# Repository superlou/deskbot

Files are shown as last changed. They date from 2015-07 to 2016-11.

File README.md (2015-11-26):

# deskbot

The boring desktop robot.

# Installation

Install pi-blaster.

    sudo apt-get install python-smbus i2c-tools
    sudo raspi-config

In the config menu, advanced options, enable automatic loading of the I2C kernel module.  Still [had to add](https://forums.adafruit.com/viewtopic.php?f=47&t=74517&sid=16e9d784a04c41fe58b5d3ec6f3fdb2d) the following to /etc/modules:

    i2c-bcm2708
    i2c-dev

May need to do some of [manual configuration steps](https://learn.adafruit.com/adafruits-raspberry-pi-lesson-4-gpio-setup/configuring-i2c).

Test with `sudo i2cdetect -y 0`.

For scipy:
    sudo apt-get install liblapack-dev gfortran
    pip install scipy # or, alternatively the following line
    sudo apt-get install python-scipy # not up-to-date, but installs much faster

Run Servo IK test with `python -m code.servo_test_ik`.

Need a relatively recent install of cython (which takes a long time to build via `pip`).  Required increase swap size per http://raspberrypi.stackexchange.com/questions/70/how-to-set-up-swap-space.

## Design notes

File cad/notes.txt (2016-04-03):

Servo mounting screws: https://www.servocity.com/html/mounting_screws.html
Length: 0.575" - measure directly under the head of the fastener (measures how much is inset in the material)
Screw diameter: 0.087"
Head diameter: 0.235"

https://www.boltdepot.com/fastener-information/Measuring/Measure-Diameter.aspx

Measuring the ones included with the HS-311 kit:
Thread (major) diameter: 0.088, Shank Diameter: 0.082, Root (minor) Diameter: ~0.050

https://www.boltdepot.com/fastener-information/Wood-Screws/Wood-Screw-Diameter.aspx

It's probably 9/16" length, #2 size wood screw.  Hole should be at least 0.600" deep, 1/16" straight bit 0.062" diameter.

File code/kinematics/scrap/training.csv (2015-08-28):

theta0 | theta1 | theta2 | phi0 | phi1 | phi2 | centroid_x | centroid_y | centroid_z | normal_x | normal_y | normal_z
-0.051979459788405125 | -0.4153607124880795 | -0.26255196620026755 | 1.08128773900578 | 0.975005773234984 | 1.12393933345835 | -0.022594617238130905 | 0.010614179645496158 | 0.6323523142335397 | 0.21807871561932096 | 0.3433888640516431 | 0.913523815693466
0.12345850232011135 | 0.10087838873966659 | 0.25844978307539723 | 1.12769162593424 | 1.12680125790354 | 1.08719967708002 | 0.0021035898199976235 | -0.0023250499304069416 | 1.057076878362002 | 0.13716029233399246 | -0.052839453500310656 | 0.9891385374964634
0.023972055089184763 | 0.24487759738520898 | 0.04804075004576591 | 1.1308020782987 | 1.07947775593959 | 1.13601836820659 | -0.006322161821066707 | -0.0017862178089064578 | 1.0026196165669914 | -0.16916325011422875 | -0.12799118372169088 | 0.97724206402524
-0.26988111103215773 | -0.35166023097420485 | 0.13644442227586284 | 1.12419130494064 | 1.02327478709782 | 1.00857168013845 | 0.018590912802977384 | -0.03195552531292881 | 0.7089183238733797 | 0.4727323118827423 | -0.1275076363458139 | 0.8719323161665138
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

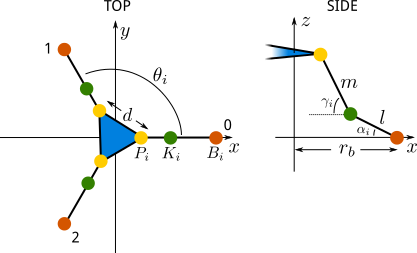
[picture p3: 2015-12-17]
diagrams/forward_kinematic_model.png

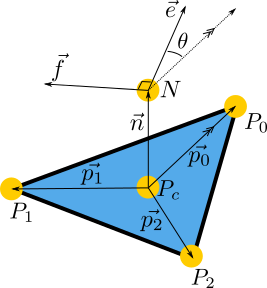
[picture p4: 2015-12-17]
diagrams/head_ik_model.png

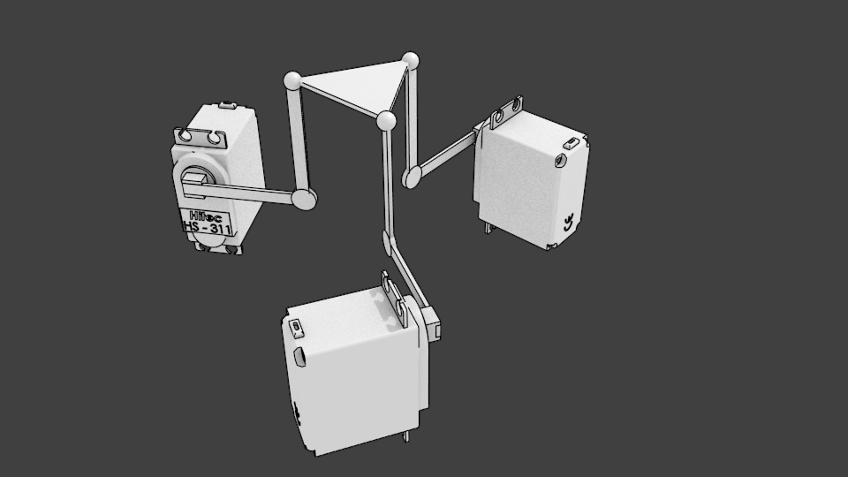
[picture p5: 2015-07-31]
blender/mockup.png

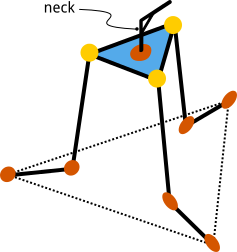
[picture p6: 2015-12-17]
diagrams/system_with_neck.png

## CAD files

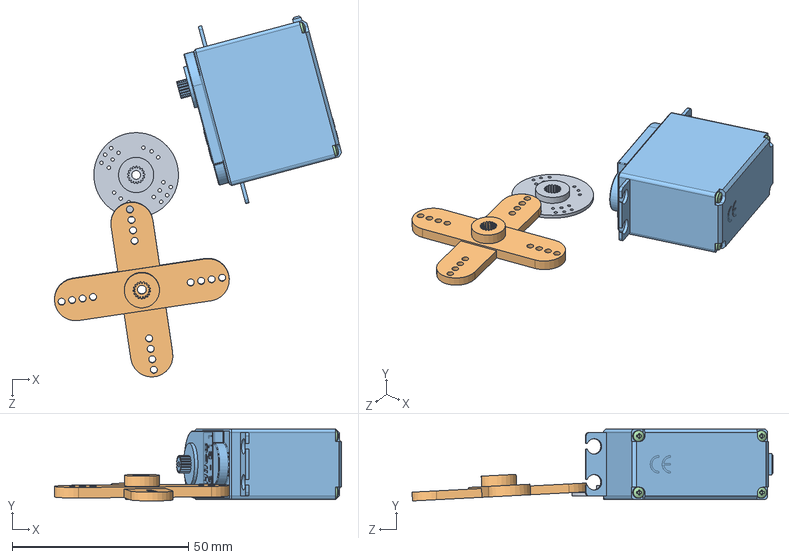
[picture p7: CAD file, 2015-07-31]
cad/servo/Hitec HS-311 Servo Motor/Hitec HS-311.SLDASM
81.4 x 20.4 x 102.3 mm
Spline
Spline 2
Hitec Servo Motor HS-311
pan head cross recess screw_din x 4

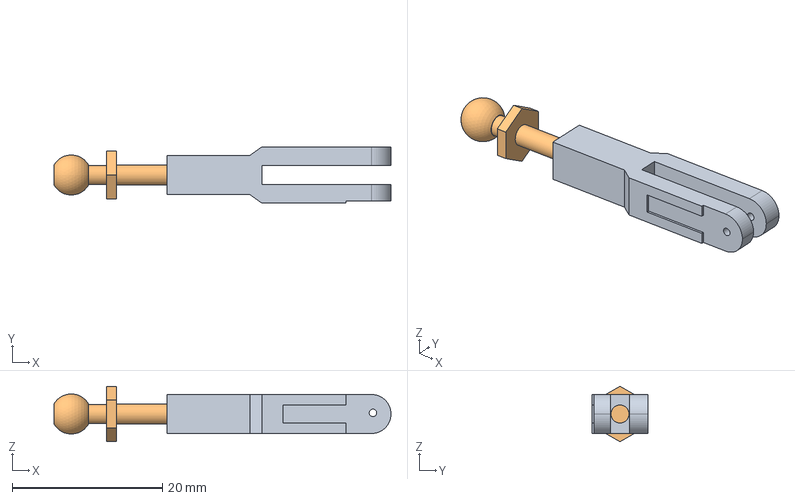
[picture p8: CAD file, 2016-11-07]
cad/clevis_ball_assembly.fcstd
44.9 x 7.50 x 7.39 mm
clevis_01
threaded_ball_01

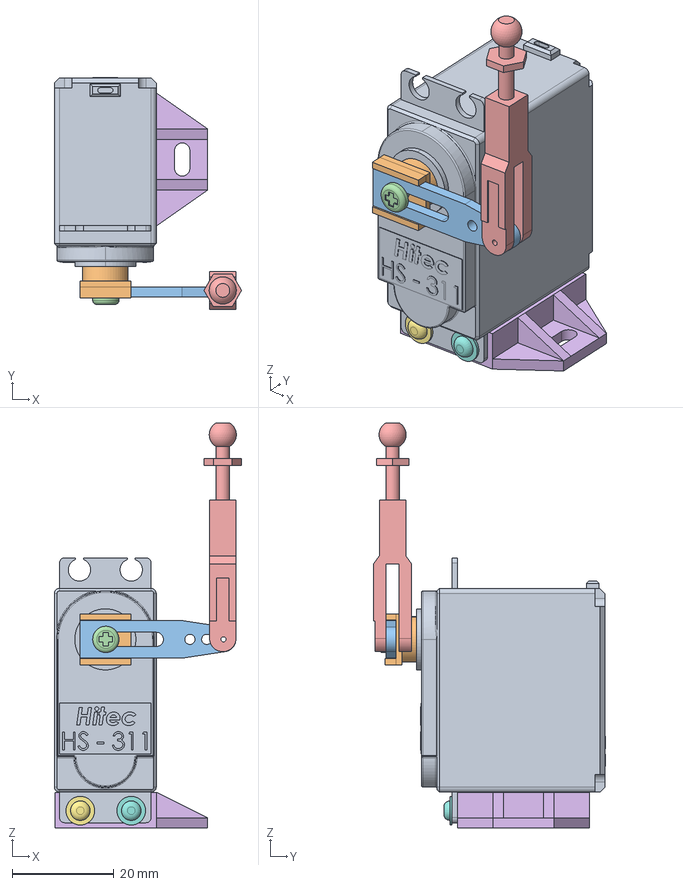
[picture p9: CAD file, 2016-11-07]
cad/servo_assembly.fcstd
36.7 x 45.6 x 79.5 mm
servo_hs_311_01
hs_311_pinion_adapter_01
servo_horn_01
hs_311_pinion_screw_01
clevis_ball_assembly_01
flat_servo_stand_01
hs_311_screw_01
hs_311_screw_01001

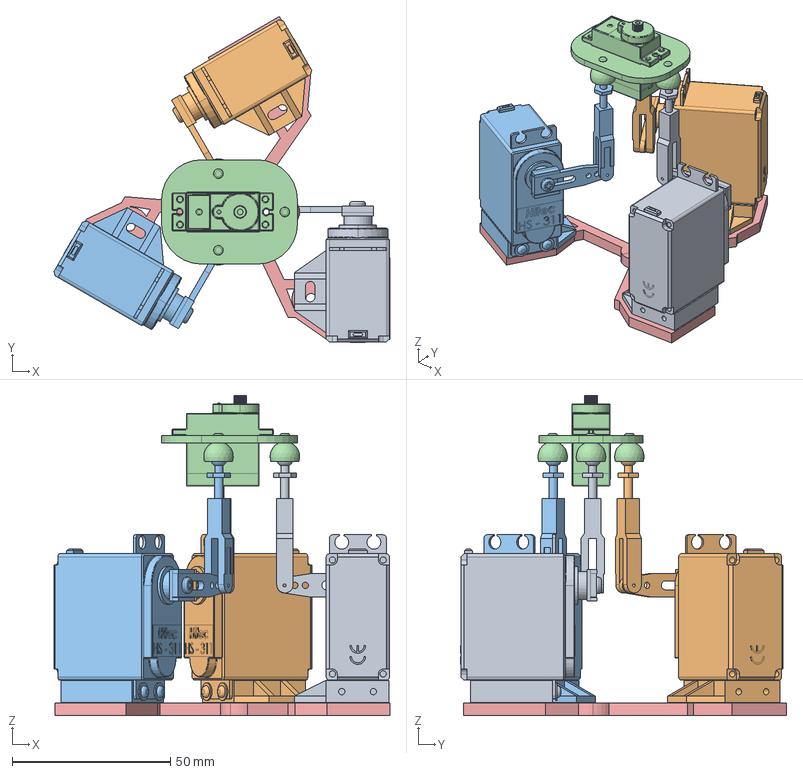
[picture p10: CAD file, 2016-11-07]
cad/kinematics_assembly.fcstd
106.3 x 103.1 x 101.4 mm
servo_assembly_01
servo_assembly_02
servo_assembly_03
head_assembly_01
base_full_01

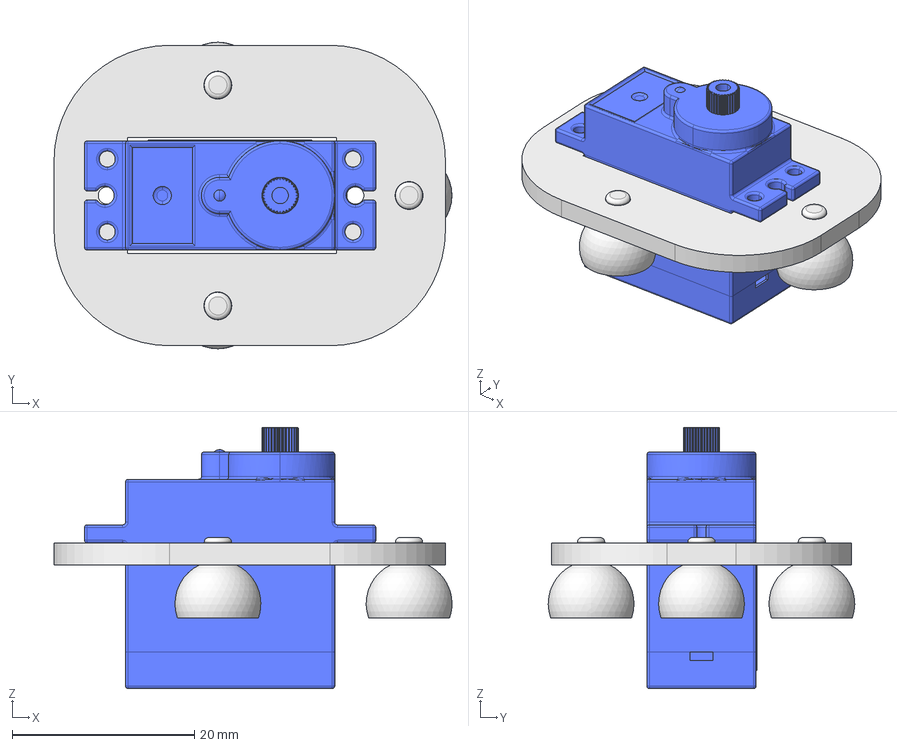
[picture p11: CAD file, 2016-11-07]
cad/head_assembly.fcstd
43.7 x 33.7 x 28.7 mm
head_mount_flat_01
socket_pin_01
socket_pin_02
socket_pin_03
hxt900_01

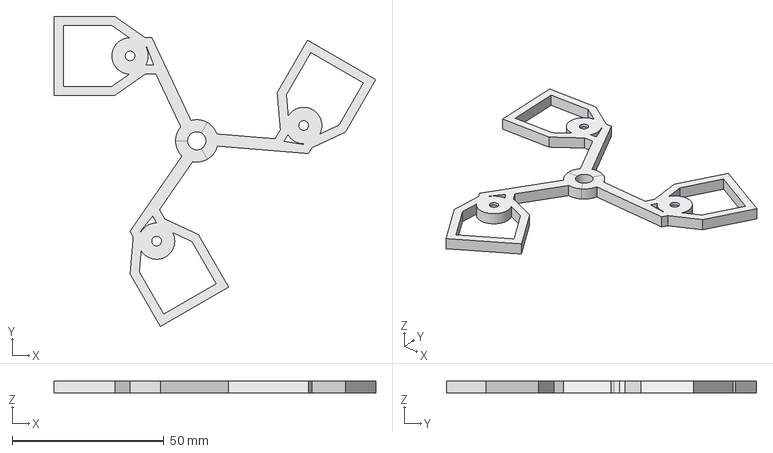
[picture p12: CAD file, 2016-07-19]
cad/base_full.fcstd
106.0 x 102.2 x 4.00 mm

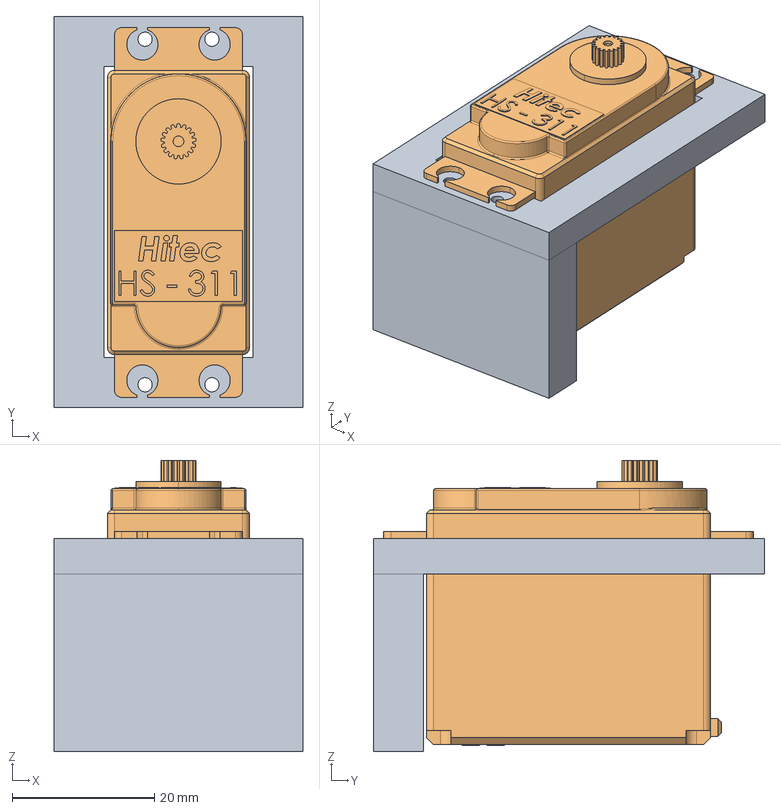
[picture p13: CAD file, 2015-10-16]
cad/vertical_servo_assembly.fcstd
35.0 x 55.0 x 41.0 mm
vertical_servo_stand_01
servo_hs_311_01

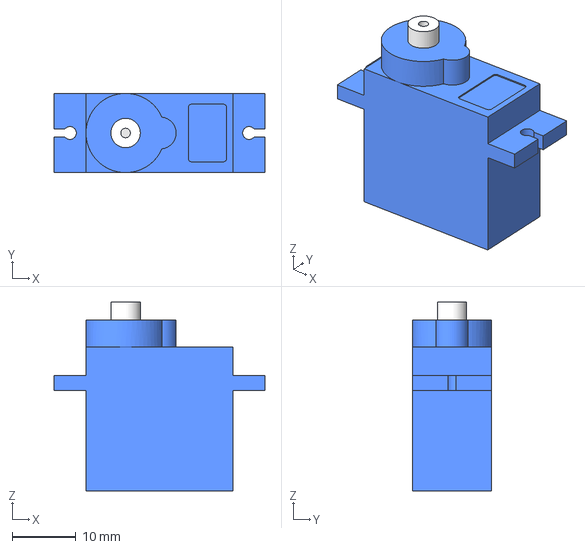
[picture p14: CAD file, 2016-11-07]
cad/HXT900/HXT900.step
33.0 x 12.4 x 29.5 mm

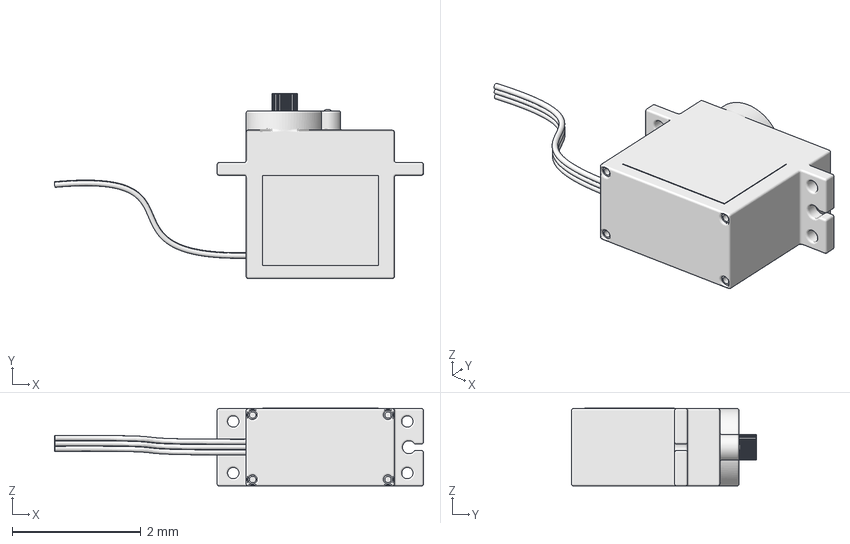
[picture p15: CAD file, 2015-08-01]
cad/micro_servo/micro_servo_all.fcstd
5.72 x 2.87 x 1.21 mm

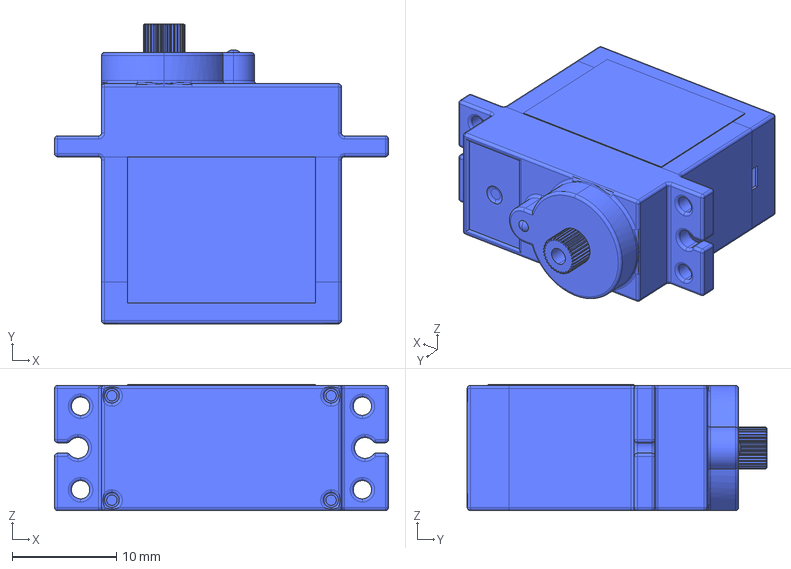
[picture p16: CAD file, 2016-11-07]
cad/servo-hxt900-micro/hxt900.fcstd
32.0 x 28.7 x 12.1 mm

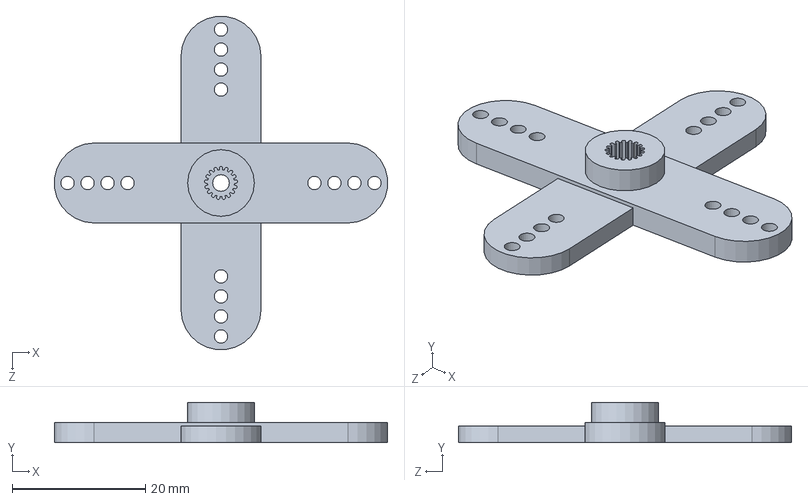
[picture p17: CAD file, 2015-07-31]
cad/servo/Hitec HS-311 Servo Motor/Spline 2.SLDPRT
49.9 x 6.00 x 49.9 mm

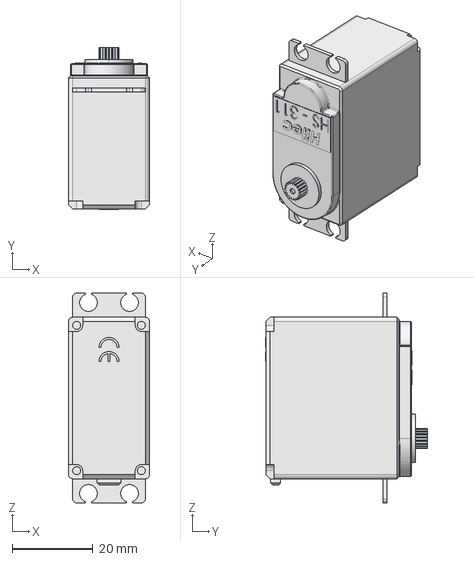
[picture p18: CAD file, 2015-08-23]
cad/servo/servo_hs-311.fcstd
20.0 x 40.1 x 52.0 mm

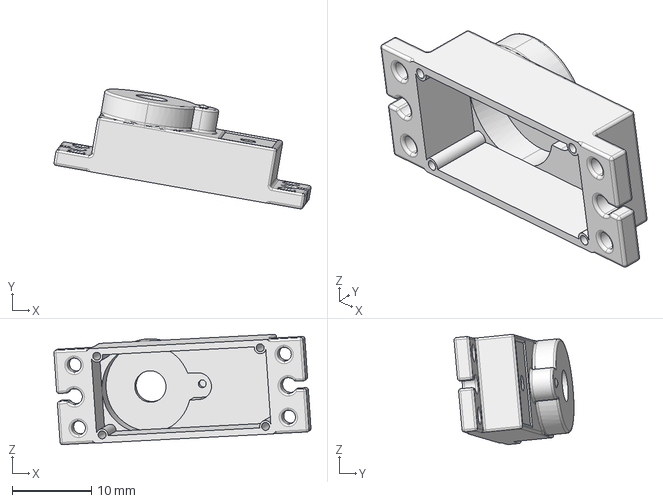
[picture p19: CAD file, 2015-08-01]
cad/micro_servo/micro_servo.fcstd
32.5 x 15.2 x 13.9 mm

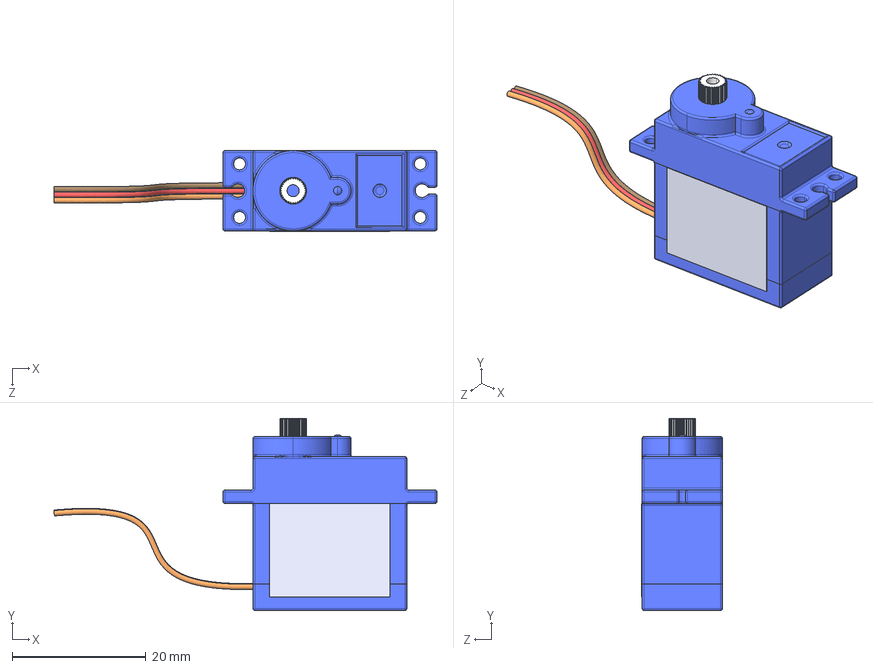
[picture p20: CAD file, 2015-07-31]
cad/servo-hxt900-micro/Servo HXT900 Micro.STEP
57.2 x 28.7 x 12.1 mm
Servo HXT900 Micro - Carcaça Intermediária
Servo HXT900 Micro - Carcaça Inferior
Servo HXT900 Micro - Carcaça Superior
Servo HXT900 Micro - Engrenagem Superior
Peça7^Servo HXT900 Micro
Servo HXT900 Micro - Fio

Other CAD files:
cad/servo/Hitec HS-311 Servo Motor/Spline.SLDPRT
cad/servo/Hitec Servo Motor HS-311.STEP
cad/servo/servo.stl
cad/servo_horn.fcstd
blender/deskbot.blend
blender/dull_black_plastic.blend
blender/ik.blend
cad/*.stl
cad/HXT900/HXT900.fcstd
cad/HXT900/HXT900.stl
cad/arm.fcstd
cad/base.fcstd
cad/base.stl
cad/base_full.stl
cad/clevis.fcstd
cad/crown.fcstd
cad/crown.stl
cad/crown2.fcstd
cad/crown2.stl
cad/flat_servo_stand.fcstd
cad/flat_servo_stand.stl
cad/head_mount.fcstd
cad/head_mount_flat.fcstd
cad/head_mount_flat.stl
cad/horn.fcstd
cad/horn.stl
cad/hs-311_pinion_adapter.fcstd
cad/hs-311_pinion_screw.fcstd
cad/hs-311_screw.fcstd
cad/plate.stl
cad/servo-hxt900-micro/Servo HXT900 Micro.SLDPRT
cad/servo-hxt900-micro/Servo HXT900 Micro.stl
cad/servo/Hitec HS-311 Servo Motor/Hitec Servo Motor HS-311.SLDPRT
cad/servo/Hitec Servo Motor HS-311.IGS
cad/servo_and_flat_stand.fcstd
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

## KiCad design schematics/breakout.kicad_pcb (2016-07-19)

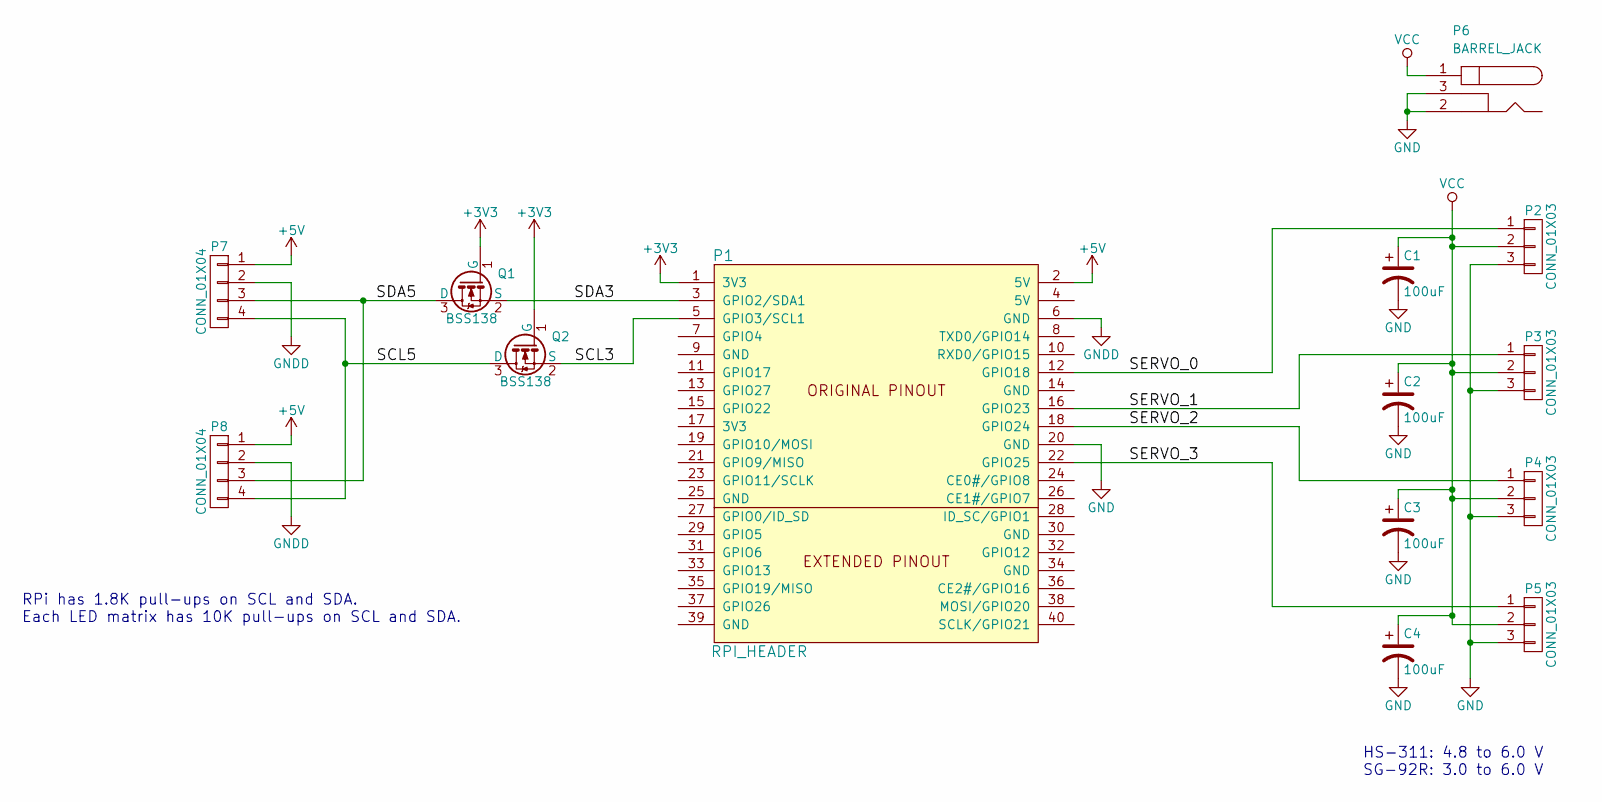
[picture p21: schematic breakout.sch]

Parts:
C1, C2, C3, C4: 100uF; C_Radial_D5_L11_P2
P1: RPI_HEADER; Pin_Header_Straight_2x20
P2, P3, P4, P5: CONN_01X03; Pin_Header_Straight_1x03
P6: BARREL_JACK
P7, P8: CONN_01X04; Pin_Header_Straight_1x04
Q1, Q2: BSS138; SOT-23

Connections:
+3V3: P1.1 (3V3), Q1.1 (G), Q2.1 (G)
+5V: P1.2 (5V), P7.1, P8.1
/SCL3: P1.5 (GPIO3/SCL1), Q2.2 (S)
/SCL5: P7.4, P8.4, Q2.3 (D)
/SDA3: P1.3 (GPIO2/SDA1), Q1.2 (S)
/SDA5: P7.3, P8.3, Q1.3 (D)
/SERVO_0: P1.12 (GPIO18), P2.1
/SERVO_1: P1.16 (GPIO23), P3.1
/SERVO_2: P1.18 (GPIO24), P4.1
/SERVO_3: P1.22 (GPIO25), P5.1
GND: C1.2, C2.2, C3.2, C4.2, P1.20 (GND), P2.3, P3.3, P4.3, P5.3, P6.2, P6.3
GNDD: P1.6 (GND), P7.2, P8.2
VCC: C1.1, C2.1, C3.1, C4.1, P2.2, P3.2, P4.2, P5.2, P6.1

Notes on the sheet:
HS-311: 4.8 to 6.0 V SG-92R: 3.0 to 6.0 V
RPi has 1.8K pull-ups on SCL and SDA. Each LED matrix has 10K pull-ups on SCL and SDA.

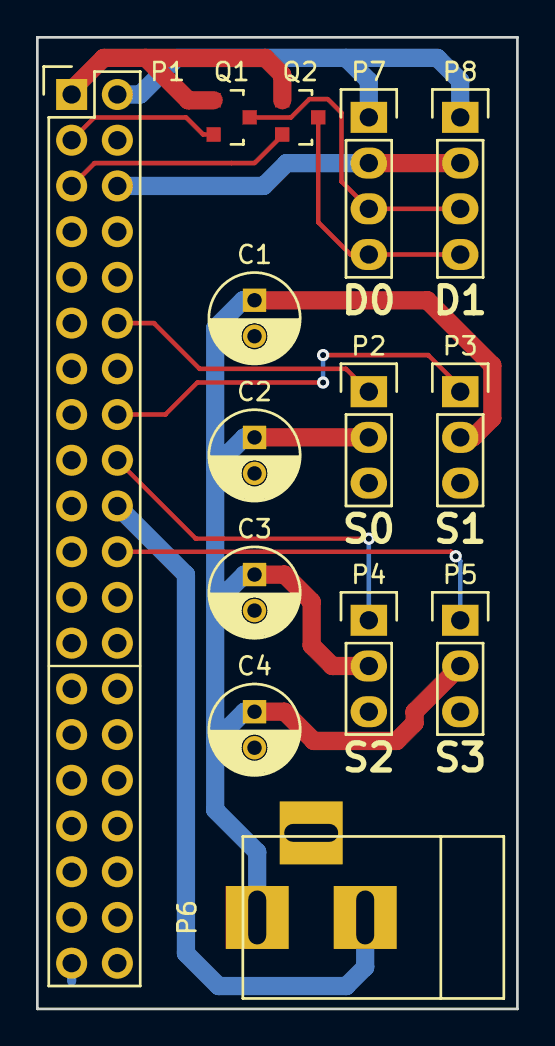
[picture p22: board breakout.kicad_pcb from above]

Board: 2 copper layers, 26.7 x 54.0 mm, 14 parts (0 on the bottom side), 13 nets.

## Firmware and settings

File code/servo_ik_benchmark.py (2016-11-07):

import sys
import signal
import time
import numpy as np
from pi_blaster_servos import PiBlasterServos
from kinematics.inverse.full_ik import FullIK
from kinematics.utilities import rotate_vector
import cProfile as profile
import pyximport
pyximport.install()
from servo_fast import ServoFast as Servo

def reset_servos(pbs):
    pbs[0] = 0
    pbs[1] = 0
    pbs[2] = 0
    pbs[3] = 0


def set_servo_angles(pbs, angles):
    start = time.time()
    if not any(np.isnan(angles)):
        pbs[0] = angles[0]
        pbs[1] = angles[1]
        pbs[2] = angles[2]
        pbs[3] = angles[3]
    # print time.time() - start

def behavior(pbs, full_ik, f_v, t, freq):
    start_time = time.time()
    y_t = 0.3 * np.cos(2 * np.pi * freq * t)
    z_t = 0.3 * np.sin(2 * np.pi * freq * t)
    e_v = np.array([1, y_t, z_t])
    e_v = e_v / np.linalg.norm(e_v)

    angles = full_ik.solve(e_v, f_v, height)
    set_servo_angles(pbs, angles)

    dt = time.time() - start_time
    t += dt
    # print(dt)
    return t


if __name__ == "__main__":
    print('Starting')
    s0 = Servo(0.15, 0.065, 0.225)  # HS-311
    s1 = Servo(0.15, 0.065, 0.225)
    s2 = Servo(0.15, 0.065, 0.225)
    s3 = Servo(0.15, 0.245, 0.055)  # SG92R
    pbs = PiBlasterServos()
    pbs.add(s0, 18)
    pbs.add(s1, 23)
    pbs.add(s2, 24)
    pbs.add(s3, 25)

    reset_servos(pbs)

    def on_terminate(signal, frame):
        reset_servos(pbs)
        pbs.turn_off()
        sys.exit()

    signal.signal(signal.SIGINT, on_terminate)


    full_ik = FullIK(platform_radius=1.42, neck_length=2.04, base_radius=3.35,
                     lower_leg_length=2.37, upper_leg_length=3.77)


    e_v = np.array([1, 0, 0])
    f_v = np.array([0, 1, 0])
    height = 6
    angles = full_ik.solve(e_v, f_v, height)
    set_servo_angles(pbs, angles)

    t = 0
    dt = 0
    freq = 1.0

    while True:
        t = behavior(pbs, full_ik, f_v, t, freq)

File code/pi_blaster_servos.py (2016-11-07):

import os


class PiBlasterServos(object):
    def __init__(self, device="/dev/pi-blaster"):
        self.servos = []
        self.angles = []
        self.pins = []

        self.device = open(device, 'w', 0)

    def add(self, servo, pin):
        self.servos.append(servo)
        self.angles.append(None)
        self.pins.append(pin)

    def __getitem__(self, key):
        return self.angles[key]

    def __setitem__(self, key, value):
        self.angles[key] = value
        period = self.servos[key].period_for_angle(value)

        command = "{0}={1}\n".format(self.pins[key], period)
        self.device.write(command)

    def turn_off(self):
        pass

    def close(self):
        self.device.close()

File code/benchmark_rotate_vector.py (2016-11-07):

import cProfile as profile
import numpy
import sys
from numpy import radians, array
from kinematics.inverse.platform_ik import rotate_vector
import pyximport
pyximport.install(setup_args={'include_dirs': numpy.get_include()})
from kinematics.inverse.utilities import rotate_vector_fast

if __name__ == "__main__":
    e_v = array([1., 0., 0.])
    gy_v = array([0., 1., 0.])
    angle = radians(10.)

    if len(sys.argv) > 1:
        runs = int(sys.argv[1])
    else:
        runs = 1

    profile.run("for i in range(runs): rotate_vector(e_v, gy_v, angle)")
    profile.run("for i in range(runs): rotate_vector_fast(e_v, gy_v, angle)")

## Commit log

2015-08-01 Modifying interior features based on parts
    [head_assembly.fcstd, head_mount_flat.fcstd, head_mount_flat.stl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]
2015-08-02 Removing extra line
    [eye_frames.ods]
2015-08-03 Add pi-blaster based servo controller
2015-08-04 Test multiple servos
2015-08-13 Motor motion
2015-08-21 Adding 4th servo
2015-08-23 Starting on servo stand
    [servo_hs-311.fcstd, vertical_servo_assembly.fcstd, vertical_servo_stand.fcstd]
2015-08-25 Direct kinematics
    [training.csv]
2015-08-25 Extract to kinematic model
    [training.csv]
2015-08-28 Mostly working kinematic model
    [training.csv]
2015-10-16 Messing with alternate assembly
    [simple_stand.fcstd, vertical_servo_assembly.fcstd]
2015-10-26 Moving messy stuff
    [training.csv]
2015-10-31 Adding head vectors
    [training.csv]
2015-11-16 Analytical leg IK
    [training.csv]
2015-11-19 Basic test of servos using IK
2015-11-21 Reorganizing code
    [training.csv]
2015-11-26 Moving leg IK to cython
2015-12-17 Adding materials
    [basics.blend, really_thin_servo_stand.fcstd, really_thin_servo_stand.stl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]
2016-04-03 Added schematics and flat servo stand
    [breakout.kicad_pcb, breakout.sch, flat_servo_stand.fcstd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]
2016-07-19 Laying out breakout board
    [*.stl, base.fcstd, base.stl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]
2016-07-19 Updated layouts for order
    [breakout.kicad_pcb, breakout.sch]
2016-08-01 Optimizing servo
2016-11-07 Lots of progress
    [HXT900.fcstd, HXT900.step, HXT900.stl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]
